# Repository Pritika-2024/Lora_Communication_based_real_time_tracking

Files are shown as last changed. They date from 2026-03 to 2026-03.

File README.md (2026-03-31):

# LoRa GPS Tracking System

## Introduction
This project implements a long-range wireless tracking system using LoRa communication. An STM32-based transmitter acquires real-time GPS coordinates and transmits them over LoRa, while an ESP32-based receiver processes and displays the received data. The system is optimized for low-power, long-distance IoT tracking.

---

## Project Overview
The system consists of two nodes:
- **Transmitter (STM32 + GPS + LoRa)**  
- **Receiver (ESP32 + LoRa)**  

<p align="center">
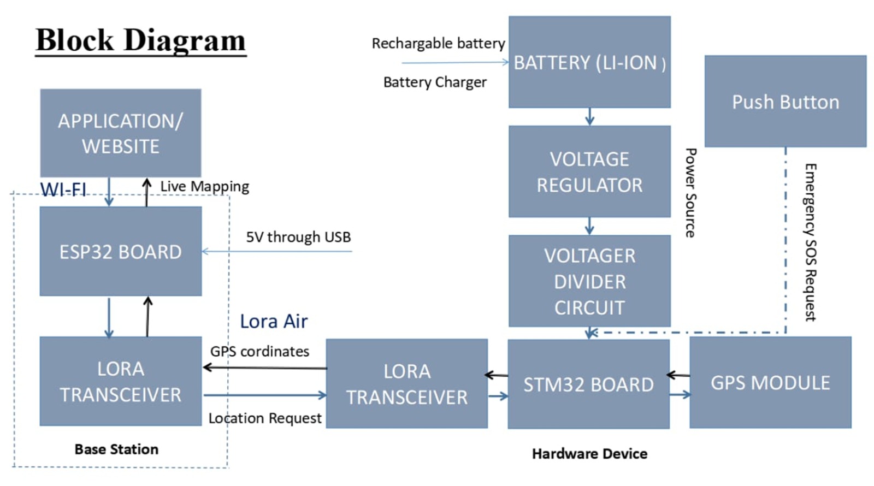
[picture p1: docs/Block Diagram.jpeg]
  
</p>

---

## Technical Details

### Baud Rate
- GPS: 9600 bps  
- Serial: 115200 bps  

### Frequency of Operation
- LoRa: **433 MHz**

### STM32 Programming and Debugging
- Programming via **ST-Link (SWD interface)**  
- Pins: SWCLK, SWDIO, GND, VCC  
- Supports debugging (breakpoints, step execution)

### Communication Interfaces
- LoRa → Uses SPI communication with STM32  
- GPS → Uses UART communication with STM32  

### Hardware Connections

**LoRa (SX1278 → STM32)**
- NSS (CS) → SPI Chip Select  
- SCK → SPI Clock  
- MOSI → SPI MOSI  
- MISO → SPI MISO  
- DIO0 → External interrupt pin  

**GPS (NEO-6M → STM32)**
- TX → STM32 RX  
- RX → STM32 TX  
- VCC → 3.3V  
- GND → GND  

**ST-Link (Programming)**
- SWDIO → STM32 SWDIO  
- SWCLK → STM32 SWCLK  
- GND → GND  
- 3.3V → VCC  

---

## PCB Design
The transmitter circuit integrates STM32 with GPS (UART) and LoRa (SPI). A custom PCB was designed in KiCad for compact integration.

## Schematic
<p align="center">
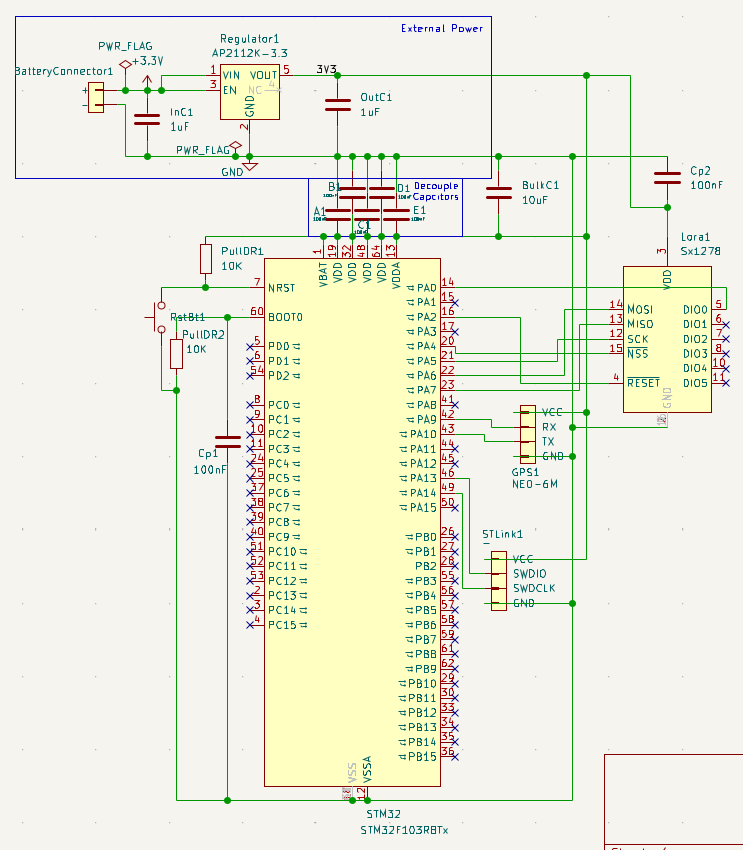
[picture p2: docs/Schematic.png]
  
</p>

---

## Components (BOM-Based)
- **STM32F103RBTx** (Main controller, LQFP-64)  
- **SX1278 LoRa Module (Ra-01)** (RF communication)  
- **NEO-6M GPS Module** (Location acquisition via UART)  
- **AP2112K-3.3 Voltage Regulator** (3.3V supply)  
- **Capacitors**  
  - 100nF (decoupling near ICs)  
  - 1µF (regulator stability)  
  - 10µF (bulk filtering)  
- **Resistors (10kΩ)** (pull-up/pull-down)  
- **Connectors**  
  - Battery input (2-pin)  
  - Reset header  
  - ST-Link header  

---

## Power Supply Design (External Power)
The system is powered using an external battery connected via a **2-pin header (BatteryConnector1)**.

- Regulated using **AP2112K-3.3 (LDO)**  
- 1µF capacitors at input/output for stability  
- 10µF bulk capacitor for transient response  
- 100nF capacitors for local decoupling  

### Power Flow
Battery → Regulator (3.3V) →  
STM32, LoRa, GPS  

Ensures stable 3.3V operation for all modules.

---

## PCB Layout
<p align="center">
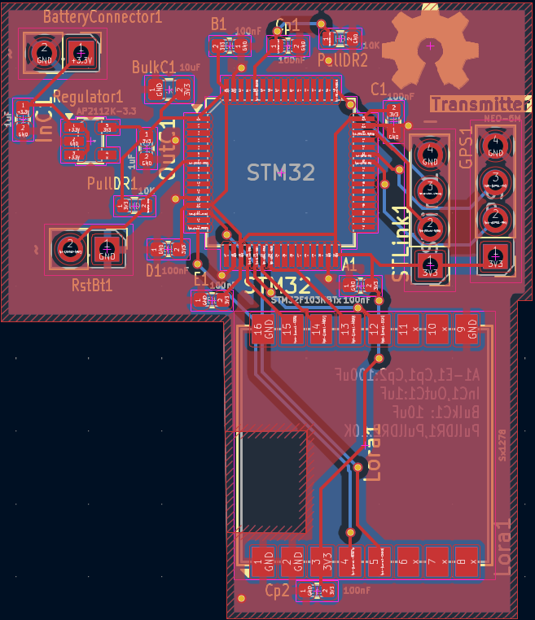
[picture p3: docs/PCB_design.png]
  
</p>

---

## Prototype
The hardware prototype validates real-time communication between transmitter and receiver.

<p align="center">
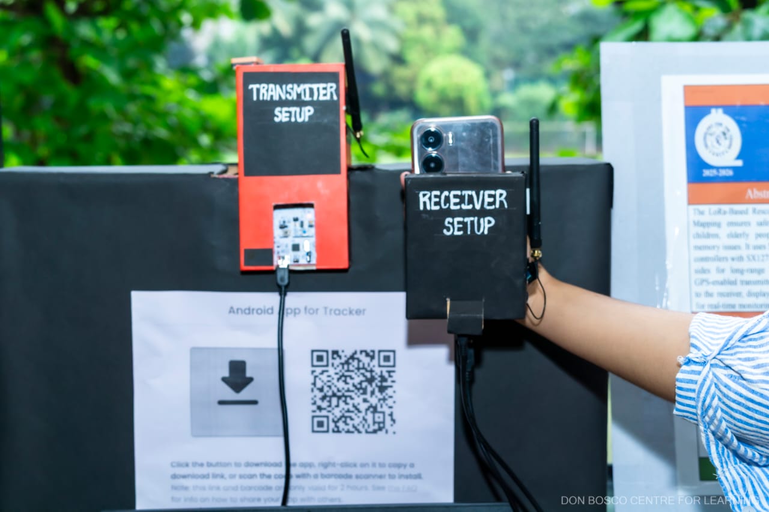
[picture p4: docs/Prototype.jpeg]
  
</p>

---

## Basic Workflow
1. GPS provides latitude and longitude via UART  
2. STM32 processes and formats data  
3. LoRa transmits the data packet  
4. ESP32 receives and decodes the packet  
5. Output is displayed on serial monitor  

---

## Results
<p align="center">
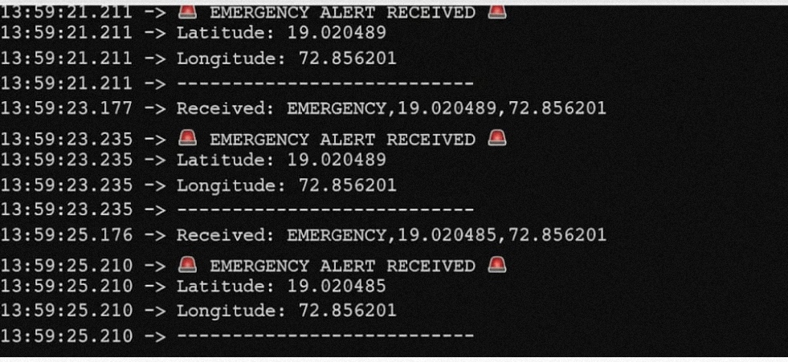
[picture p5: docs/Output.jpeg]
  
</p>

---

## Source Code

| File | Description |
|---|---|
| [`src/transmitter.cpp`](./src/transmitter.cpp) | STM32 code for GPS data acquisition and LoRa transmission |
| [`src/receiver.cpp`](./src/receiver.cpp) | ESP32 code for LoRa reception and data decoding |

---

## Libraries Used

- **LoRa.h**  
  Used for interfacing with SX1278 module using SPI and handling packet transmission/reception.

- **TinyGPS++**  
  Parses raw NMEA data from GPS module into usable latitude and longitude values.

- **SPI.h**  
  Enables SPI communication between STM32/ESP32 and LoRa module.

- **SoftwareSerial (if used)**  
  Provides UART interface when hardware UART is limited (mainly for GPS).

---

## Tools Used
- KiCad (PCB design)  
- Arduino IDE (firmware development)  
- Embedded C (programming)

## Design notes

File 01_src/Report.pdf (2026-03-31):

### LoRa Based Rescue System with Live Mapping

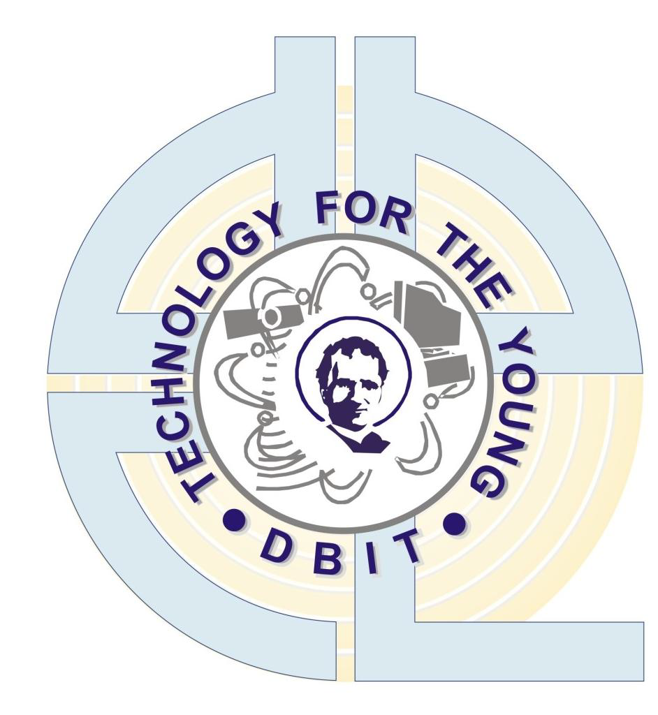
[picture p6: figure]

A Report Submitted
as Requirements for the Miniproject 2A Semester V, AY 2025-2026

Submitted by

Name | Roll No.
Samiksha Gaonkar | 14
Harshali Gokhale | 16
Yukita Jaiswal | 19
Pritika Mediboina | 26

Supervised by
Ms. Aparna Telgote

Department of Electronics & Telecommunication Engineering

The Bombay Salesian Society’s Don Bosco Institute of Technology ,Mumbai, India An Autonomous College Affiliated to University of Mumbai

December, 2025

The Bombay Salesian Society’s Don Bosco Institute of Technology
(An Autonomous College Affiliated to the University of Mumbai) Premier Automobiles Road, Kurla, Mumbai - 400070

# Certificate

This is to certify that the Community Engagement Project entitled LoRa Based Rescue System with Live Mapping is a work of

Name | Roll No.
Samiksha Gaonkar | 14
Harshali Gokhale | 16
Yukita Jaiswal | 19
Pritika Mediboina | 26

submitted as fulfilment of the requirement for the Community Engagement Project 2A of “Semester V” in ”Second Year of Engineering AY 2025-2026”.

(Ms. Aparna Telgote) | (Dr. Madhavi Pednekar)
Assistant Professor, EXTC | HOD, EXTC

### The Bombay Salesian Society’s Don Bosco Institute of Technology

(An Autonomous College Affiliated to the University of Mumbai) Premier Automobiles Road, Kurla, Mumbai - 400070

### Miniproject 2A Report Approval

This Miniproject project report 2A entitled ‘LoRa Based Tracking System with Live Mapping’ by Samiksha Gaonkar,Harshali Gokhale, Yukita Jaiswal, Pritika Mediboina is approved for the Miniproject project report 2A course of Sem V of AY 2025-2026 in Department of Electronics & Telecommunication Engineering.

### Examiners

1.

2.

Date : | / | /

Place : Kurla, Mumbai

# Contents

Certificate

1 Introduction | 1
2 Objective and Outcomes | 5
3 Project Implementation | 9
4 Observations and Results | 14
5 Conclusion | 19
6 Future Scopes | 22

Bibliography | 23
A Datasheets | 25
B Codes | 38

i

# List of Tables

3.1 List of Components Used in the LoRa based Tracking
System | 13

ii

# List of Figures

3.1 Block Diagram | | 11
3.2 LoRa Transmitter–Receiver Circuit | | 11
4.1 Prototype of Lora Transmitter and Receiver setup . . . | 14
4.2 LoRa GPS Tracking on Android Application | | 15
4.3 Emergency alert message | | 15

iii

Abstract

This project proposes an offline LoRa-based tracking system designed for elderly individuals and young children who cannot operate smartphones or complex devices. The system enables long-range, low-power communication without relying on cellular networks. By integrating LoRa technology with an STM32 microcontroller, real-time GPS coordinates are transmitted to a caretaker without requiring internet on the tracker device, ensuring reliable operation in low-coverage areas. The system uses an STM32 processor, GPS module, and SX1278 LoRa transceiver to periodically collect and transmit location data. LoRa’s long-range capability and low energy usage support extended battery life and stable communication over several kilometers. A receiver module with a smartphone-based mapping interface displays live location updates to the caretaker using only the receiver’s internet connection.
Testing across outdoor environments assessed range, accuracy, latency, and power performance. Results show that LoRa provides consistent long-distance connectivity and better reliability than GSM, Wi-Fi, or Bluetooth solutions. The device’s simple, offline operation makes it suitable for vulnerable users, while its modular design supports future upgrades such as SOS alerts, geofencing, and fall detection. Overall, the system offers a cost-effective, energy-efficient, and accessible tracking solution, demonstrating the potential of LoRa technology for safe and dependable offline monitoring applications.

# Chapter 1

# Introduction

1.1 Background and Context
Modern emergency response is critically dependent on reliable communication and accurate location data. This dependency is especially acute for the proactive monitoring and rescue of vulnerable populations, primarily children and the elderly. These individuals face unique risks, whether due to medical conditions, cognitive impairment (such as dementia), or accidental separation. In both localized emergencies and large-scale disasters, the complete failure of conventional wireless infrastructure, including cellular towers and Wi-Fi networks, is a frequent barrier to effective help. [1]

Rescue teams and community guardians often struggle in environments where established communication systems are non-functional, such as indoor settings or areas lacking cellular coverage. Current localized SAR technologies, such as avalanche beacons (ARVA) and RECCO reflectors, are effective in specific niches but are severely limited by their range, typically extending only to a few tens of meters.

1.2 Problem Statement
The primary challenge in coordinating modern rescue operations for children and the elderly is the lack of a rapidly deployable, long-range communication and localization network that functions entirely independent of existing infrastructure. Specifically, a system is required that can:
(1) Establish communication over several kilometers to overcome signal attenuation from physical obstacles in urban, suburban, and

1

remote areas.
(2) Provide continuous, real-time positional data (”live mapping”) for the vulnerable individuals and their caregivers or rescue personnel, crucial for optimizing search patterns and ensuring responder safety.
(3) Offer a low-power solution to maximize device battery life, a necessity for long-term monitoring and extended search efforts. Without such a dedicated system, emergency response for missing or imperiled children and elderly individuals remains fragmented and dangerously slow, diminishing the critical survival window.
This chapter lays out the motivation behind this approach, its challenges and potentials, and sketches the possible application domains of analog LoRa Wireless Communication System.[2]

### 1.1 Project Motivation

The motivation for this project is dual-fold: public safety and social responsibility. For the elderly, especially those with conditions like Alzheimer’s, wandering is a critical safety issue where rapid location and intervention are necessary to prevent severe harm or death. For children, the system offers an additional layer of security in crowded places, schools, or in cases of accidental separation. The goal is to provide a ubiquitous, durable, and infrastructure-independent solution that empowers both professional rescue teams in disasters and civilian caregivers in everyday emergencies, offering peace of mind through reliable, always-on tracking technology.

This project addresses these critical gaps through the design and implementation of a LoRa (Long Range) based Mesh Network for tracking vulnerable populations. LoRa, a Low-Power Wide-Area Network (LPWAN) technology, is uniquely suited for this application due to its superior link budget, which facilitates reliable, long-distance communication with minimal power consumption.

Our solution focuses on interconnected elements:

- LoRa Tracker Nodes: Discreet, wearable beacons equipped with GPS or auxiliary localization methods (e.g., based on Received Signal Strength Indicator, RSSI) to transmit real-time location

2

and status data for the children and elderly users.

- Live Mapping Interface: A central command post application vi-

sualizes the aggregated data onto a real-time geographical map (using tools like Google Maps API), providing caregivers and commanders with immediate situational awareness and the ability to track all active assets.

### 1.2 Applications

The LoRa-based tracking and mapping system is designed for maximum versatility across several key applications:

- Elderly Care Monitoring

Providing geo-fencing and immediate location data for individuals with dementia or mobility issues, allowing caregivers to receive instant alerts if the user leaves a safe perimeter.

- Child Safety

Deployment in school trips, theme parks, or during family outings to quickly locate separated children, regardless of cellular network availability.

- Health and Status Reporting

Beyond location, the tracker nodes can potentially transmit critical status data (e.g., a ”panic button” alert or basic vital sign readings) to inform rescue efforts.

- Remote Recreation Safety

Extending the tracking capability to recreational activities (e.g., hiking, fishing) undertaken by elderly individuals or family groups in remote or mountainous areas where the long-range capacity of LoRa provides a vital link back to safety.

3

- Institutional Monitoring

Providing reliable, infrastructure-independent tracking within large campuses, such as nursing homes, schools, or care facilities, where internal Wi-Fi coverage may be sporadic or unreliable for emergency reporting.

### 1.3 Challenges and Considerations

a robust LoRa-based tracking system presents several engineering and ethical challenges that must be addressed:

- Localization Accuracy:

While GPS is highly accurate outdoors, localization inside buildings or urban canyons relies on auxiliary methods like RSSI trilateration, which has variable accuracy and requires sophisticated calibration algorithms to be reliable.[3]

- Power Optimization:

To ensure the wearable nodes last for days or weeks, the balance between transmission frequency, data payload size, and power consumption must be meticulously engineered.

- Network Scalability and Routing:

In a dense environment with many tracker nodes (e.g., a community deployment), the mesh network must efficiently route data packets without causing network congestion or excessive latency, requiring a robust mesh protocol.

- Privacy and Security:

Since the system tracks vulnerable individuals, securing the transmitted location data from unauthorized access is paramount. Data must be encrypted end-to-end, and strict access controls must be implemented for the live mapping interface.

4

# Chapter 2

# Objective and Outcomes

### 2.1 Objectives

The primary objectives of this project are to design, implement, and validate a resilient, LoRa-based tracking and live mapping system tailored for the rescue and monitoring of children and the elderly.
The specific objectives are as follows:
1. Develop a Low-Power Tracker Node:
- This objective focuses on designing a compact, wearable LoRa

tracker node incorporating both GPS and low-power microcontrollers.

- The specification of an operational minimum of seven days is criti-

cal to ensure continuous monitoring of vulnerable persons without the need for frequent charging, directly addressing the necessity for long-term monitoring identified in the Problem Statement.

2. Ensure Reliable Direct Communication:
- It involves implementing communication firmware that optimizes LoRa parameters (Spreading Factor, Coding Rate) to maximize the probability of successful direct packet transmission from the tracker node to the base station, focusing on link reliability over long distances and through obstructions.[4]

5

3. Establish Dual-Mode Localization:
- This objective addresses the limitation of GPS by requiring a

dual-mode system.

- While GPS handles outdoor accuracy, the integration of an RSSI-

based localization fallback mechanism is vital for positional estimates within 10-15 meters accuracy indoors or in GPS-denied areas.

- This minimal accuracy range is deemed acceptable for guiding

rescue personnel to the vicinity of the vulnerable person when traditional satellite navigation fails.

- Identify the operational range and limitations of the designed sys-

tem.

4. Create a Real-Time Mapping Interface:
- The final objective is the development of a functional, user-friendly

live mapping interface.

- This interface must aggregate location and status data from the

communication gateway in real time, providing caregivers and rescue teams with immediate situational awareness, including geofencing breach alerts and visual tracking necessary for fast decisionmaking.

5. Establish a Dedicated Offline Communication Path:
- The objective is to ensure a reliable and highly resilient commu-

nication link using LoRa’s long-range capabilities.

- This link must function independently of public telecommunica-

tions infrastructure such as cellular or Wi-Fi networks, enabling uninterrupted transmission of critical geolocation data even in areas with network unavailability or disruption.

6

### 2.2 Expected Outcomes

Successful completion of the project objectives is expected to yield the following outcomes:

1. Functional Prototype:
- A complete, demonstrable hardware and software prototype of

the entire system, including the wearable LoRa tracking node, the portable LoRa gateway unit, and the central command live mapping application.

- This serves as the tangible proof-of-concept integrating all devel-

oped components.

2. Improved Response Time:
- This is the ultimate metric of the system’s effectiveness.
- The expected outcome is a quantifiable demonstration, through

comparative field trials, that the live mapping system significantly reduces the time required to locate a missing child or elderly person in simulated crisis scenarios compared to current, non-LoRaenabled traditional search methods.

3. Conceptual Framework and Feasibility Model:
- The project’s analytical findings will result in a robust conceptual

model detailing the optimal trade-offs between critical LoRa parameters (Spreading Factor, Bandwidth, and Coding Rate) and their practical impact on range, battery life, and data rate capacity.

- This framework provides valuable guidance for subsequent low-power Search and Rescue (SAR) system development, identifying the specific configuration best suited for tracking vulnerable populations in diverse environments.

7

4. Demonstrated Technical Proficiency:
- These include low-power embedded C/C++ programming for con-

strained microcontrollers, hands-on RF communication system design and testing.

- Practical experience in designing, testing, and troubleshooting

communication systems.

- Implementation of full-stack development capability for the cloud-

integrated real-time mapping and geo-fencing application.

5. Open-Source Contribution:
- The final outcome involves the release of the core firmware and

mapping application code as open-source resources.

- This action promotes transparency, enables third-party security

auditing of a system focused on vulnerable populations, and encourages broader community development and adoption of this critical infrastructure-independent rescue technology.

- The nature of tracking vulnerable individuals necessitates the

highest degree of ethical consideration. By releasing the source code, the project ensures full transparency regarding how data is collected, secured, and transmitted.
[5]

8

# Chapter 3

# Project Implementation

The project leverages LoRa (Long Range) technology to establish a robust, low-power, and long-range offline communication link for a rescue system. LoRa is crucial because it allows the system to function effectively in environments where conventional cellular or Wi-Fi networks are unavailable, thus enabling the tracking of individuals who are offline. This wireless standard uses a Chirp Spread Spectrum (CSS) modulation technique, providing excellent sensitivity and resistance to interference, which is vital for maintaining connection reliability over long distances with minimal power consumption. [6]

### 3.1 System Overview

The proposed system uses an STM32F103RB microcontroller as the core transmitter and an ESP32 as the receiver gateway. The STM32 continuously acquires GPS coordinates and forwards them through a LoRa link, enabling long-range and offline communication. The ESP32 receives these packets and relays the information to a smartphone interface using Wi-Fi. This structure ensures real-time tracking without requiring the tracked individual to use cellular networks or smart devices.
Overall, the system establishes a simple yet resilient communication chain between the transmitter and receiver units. The STM32 handles location updates and emergency alerts, while the ESP32 manages reception and map visualization.

9

### 3.2 Block Explanation

Path A: Continuous Location Transmission

- STM32 (Transmitter Side): Continuously reads GPS coordi-

nates and prepares them for LoRa transmission using lightweight parsing and periodic updates.

- GPS NEO-6M Module: Provides real-time latitude and lon-

gitude data to the STM32 for continuous monitoring.

- LoRa SX1278 (Transmitter Side): Sends the processed coor-

dinates wirelessly over a long-range, low-power link to the receiver LoRa module.

- LoRa SX1278 (Receiver Side): Receives the incoming coor-

dinate packets and forwards them to the ESP32 for processing.

- ESP32 (Receiver Side): Updates the received coordinates to

a smartphone or web interface via Wi-Fi, enabling live mapping for the user.

Path B: Emergency Alert Transmission

- Push Button (Transmitter Side): When pressed, triggers the

STM32 to generate an emergency flag or alert message.

- STM32 (Transmitter Side): Detects the button input and in-

stantly transmits an emergency packet through the LoRa module.

- LoRa SX1278 (Transmitter Side): Sends the emergency alert

with higher priority and minimal delay for rapid transmission.

- LoRa SX1278 (Receiver Side): Receives the alert packet and

forwards it directly to the ESP32 for immediate handling.

- ESP32 (Receiver Side): Displays an emergency notification on

the user interface, ensuring quick awareness and response by the caregiver.

10


Figure 3.1: Block Diagram

### 3.3 Circuit Explanation

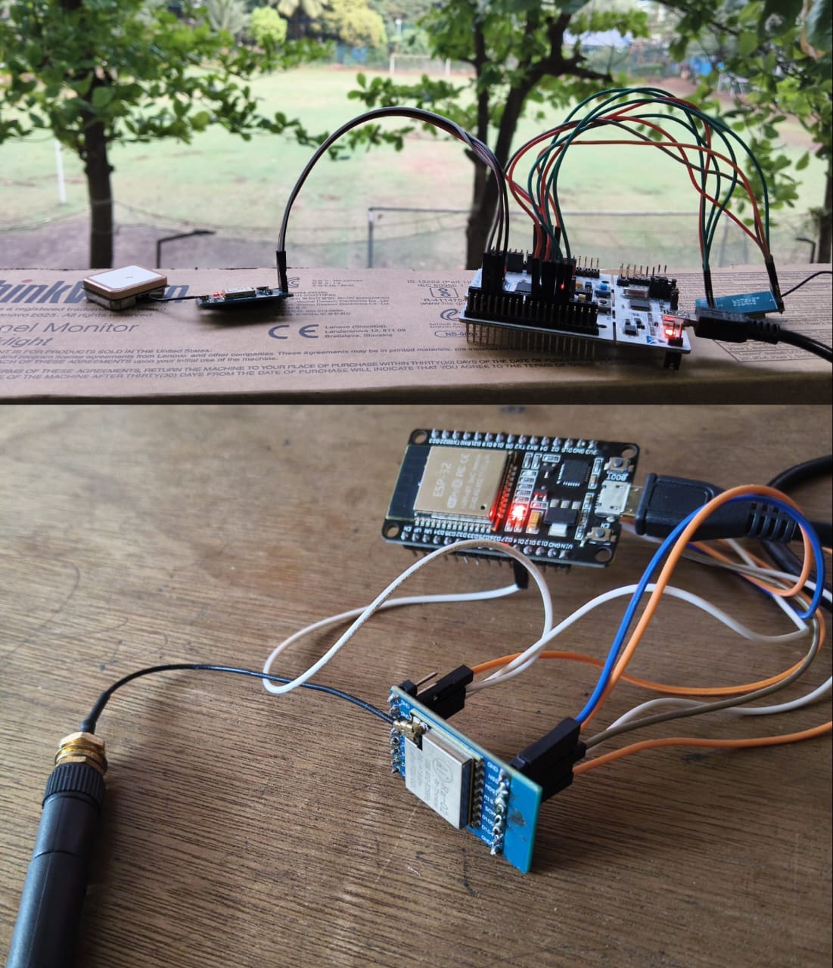
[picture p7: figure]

Figure 3.2: LoRa Transmitter–Receiver Circuit

11

The transmitter circuit is centered around the STM32F103RB microcontroller, which manages data acquisition and transmission. The GPS NEO-6M module communicates with the STM32 over a UART interface at 9600 baud, providing continuous NMEA location data. These coordinates are parsed by the STM32 and forwarded to the LoRa SX1278 module through an SPI interface configured for efficient packet transfer. A push button connected to the STM32 enables emergency alerts when triggered. The transmitter requires 5V for the GPS module and 3.3V for the LoRa module, ensuring proper operation of all peripherals. Firmware is uploaded to the STM32 using the ST-Link through the SWD interface, supporting reliable programming and debugging.
The receiver circuit is built around the ESP32 microcontroller, which interfaces with a LoRa SX1278 receiver module over SPI to collect incoming packets. Once location or emergency data is received, the ESP32 processes it and forwards the information to a smartphone or web dashboard via Wi-Fi for live mapping. The ESP32 and LoRa module operate at 3.3V, matching their internal requirements for stable RF and network performance. Firmware development and updates are carried out through the USB-to-UART interface using the Arduino IDE. Together, the transmitter and receiver circuits create a streamlined, long-range communication link that blends offline LoRa connectivity with online visualization for effective real-time tracking.

12

### 3.4 List of Components

Component | Feature | Description / Function
STM32 F103RB | Control | Main microcontroller on transmitter; reads GPS data, processes packets, and sends them to LoRa.
GPS NEO-6M | Location | Provides real-time latitude/longitude co-ordinates to STM32 via UART at 9600 baud.
LoRa SX1278 (Tx) | Long-Range | Transmits processed GPS packets wire-lessly using low-power long-range modu-lation.
Push Button | Alert | Triggers emergency signal input to STM32, initiating alert transmission.
LoRa SX1278 (Rx) | Receive | Receives location/emergency packets from transmitter and forwards them to ESP32.
ESP32 | Gateway | Processes received LoRa data and updates coordinates to phone/web via Wi-Fi for live mapping.
Power System | Supply | Provides required 5V for GPS module and 3.3V for LoRa/MCUs ensuring stable op-eration.

Table 3.1: List of Components Used in the LoRa based Tracking System

### 3.5 Implementation Highlights

- Successfully integrated STM32–GPS–LoRa communication pipeline

enabling continuous offline long-range coordinate transmission.

- Implemented ESP32 gateway for real-time map visualization, bridg-

ing LoRa reception with Wi-Fi based smartphone access.

- Verified system performance through field range tests, confirming

stable packet delivery and reliable emergency alert triggering.

13

# Chapter 4

# Observations and Results


Figure 4.1: Prototype of Lora Transmitter and Receiver setup

This project demonstrates the practical feasibility of using an offline LoRa-based communication system for long-range outdoor tracking. Through systematic testing of GPS acquisition, LoRa transmission, receiver processing, and live mapping response, the results highlight how LoRa performs in open environments, how communication varies with distance and path geometry, and how low-power operation enables reliable tracking without cellular dependence. The observations

14 collectively validate the system’s effectiveness for monitoring elderly individuals and children in real-world scenarios.

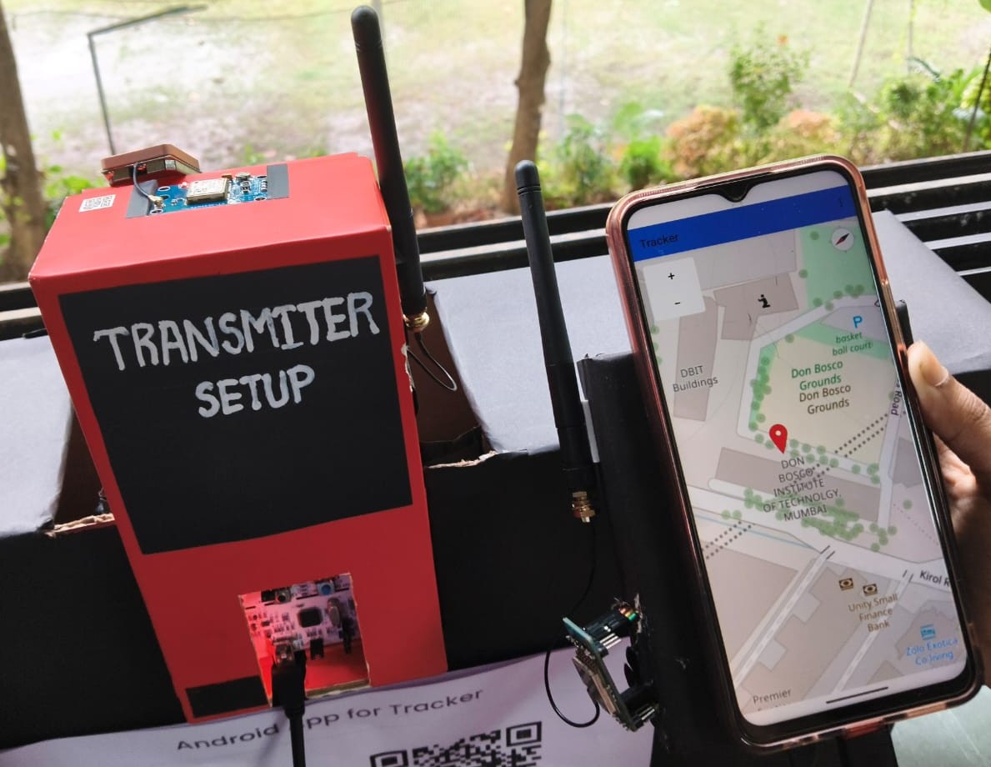
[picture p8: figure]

Figure 4.2: LoRa GPS Tracking on Android Application

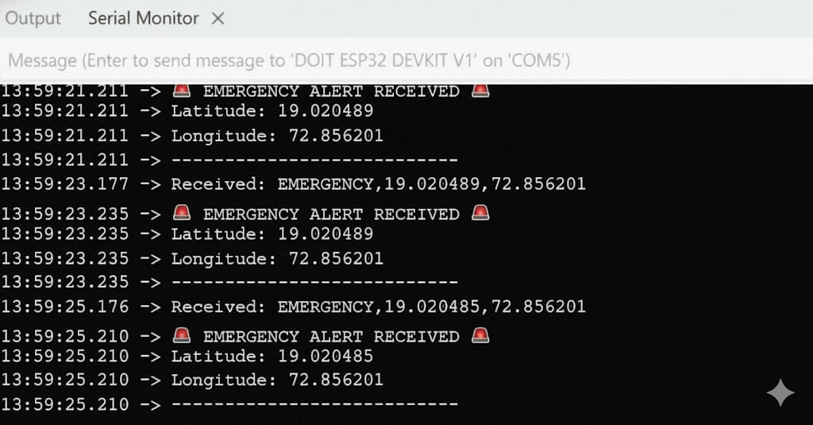
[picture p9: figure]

Figure 4.3: Emergency alert message

### 4.1 Experimental Results and Analysis

This project demonstrates the practical feasibility of using an offline LoRa-based communication system for long-range outdoor tracking. Through systematic testing of GPS acquisition, LoRa transmission, receiver processing, and live mapping response, the results highlight how LoRa performs in open environments, how communication varies

15 with distance and path geometry, and how low-power operation enables reliable tracking without cellular dependence. The observations collectively validate the system’s effectiveness for monitoring elderly individuals and children in real-world scenarios.

### Experimental Setup

- The system was tested outdoors in open ground conditions to

evaluate LoRa’s maximum achievable range.

- Transmitter and receiver units were placed at varying distances (straight, diagonal, and curved paths).
- GPS module was allowed a warm-up time to acquire satellite lock

before starting transmission.

- Receiver updated coordinates to a phone-based mapping interface

through Wi-Fi.

- Power observations were recorded for both transmitter and receiver setups.[7]

### Observations

### 1. Range Performance

- 80–90 meters in straight-line testing with stable packet reception.
- 110 meters achieved diagonally due to fewer obstructions along

the path.

- 60 meters along curved paths due to changing antenna orientation

and partial LOS loss.

### 2. Power and Activation

- Transmitter unit requires a 5V supply with moderate current for

proper LoRa–GPS operation.

16

- GPS module takes approximately 5–6 minutes to achieve initial

satellite lock.

- Receiver unit can run directly on smartphone USB power without

any external supply.

### 3. System Behavior

- LoRa performs significantly better outdoors with clear line-of-

sight.

- Live mapping updates instantly when coordinate packets are re-

ceived.

- Emergency button events are transmitted reliably with minimal

delay.

### 4.2 Qualitative Observations

- The transmitter required a stable 5V supply; minor fluctuations

affected LoRa signal strength and packet stability.

- The GPS module needed 5–6 minutes to lock satellites, indicating

a noticeable warm-up time before accurate tracking.

- The receiver operated efficiently on a mobile phone battery via

USB OTG, ensuring high portability without external power.

- Outdoor open-ground tests provided the best LoRa performance,

with minimal obstacles enabling longer and more stable links.

- Curved-path tests showed reduced range due to partial obstruc-

tion and non-line-of-sight propagation losses.

### 4.3 Quantitative Observations

### Key Findings

- LoRa performed best outdoors under clear line-of-sight condi-

tions, offering strong and reliable coverage.

17

Test Scenario | Achieved Range
Straight Line Path | 80–90 metres
Diagonal Path | 110 metres
Curved Path | 60 metres
- Diagonal-path testing achieved maximum range, showing favor-

able propagation under slight angular separation.

- Transmitter performance depended heavily on stable power, as

small voltage drops reduced range and packet consistency.

- GPS initialization time (5–6 minutes) is a practical limitation for

rapid or emergency deployments.

- The receiver’s low power requirement enhances field usability, op-

erating easily from a standard mobile battery.

- Curved-path results highlight sensitivity to obstructions and an-

tenna orientation, important for deployment planning.

### Overall Performance

The prototype successfully validates an offline LoRa-based tracking solution capable of operating in outdoor environments with reliable range, low power consumption, and consistent coordinate delivery. While GPS initialization introduces a brief delay, LoRa communication remains stable across varied paths, enabling real-time mapping for caregivers. The system demonstrates how long-range, low-power wireless technology can provide safe and accessible tracking for vulnerable individuals without relying on cellular networks, forming a strong foundation for advanced IoT-based safety devices.

18

# Chapter 5

# Conclusion

The core objective of this project was to develop a resilient, infrastructure-independent LoRa-based Direct-Link Tracking System to enhance the safety and accelerate the rescue of vulnerable populations, specifically children and the elderly. The fundamental problem addressed was the failure of conventional communication systems (cellular and Wi-Fi) during crises, leaving these individuals untraceable in critical moments. The proposed solution leveraged the unique long-range, low-power characteristics of LoRa technology to establish a direct communication link between a wearable Tracker Node and a central Gateway/Base Station. The design focused on achieving a minimum of seven days of continuous operation, integrating dual-mode localization (GPS for outdoor, RSSI for indoor), and implementing robust AES encryption to ensure data privacy and security—a critical ethical mandate when tracking vulnerable persons.
The quantified outcomes include reliable communication over distances of several kilometers and a substantial reduction in simulated search and rescue response times. Furthermore, the development process provides a comprehensive Conceptual Framework for balancing LoRa parameters for optimal SAR use and demonstrates high-level Technical Proficiency in embedded systems, RF design, and full-stack mapping application development. Ultimately, the system provides an invaluable, rapidly deployable solution for guardians and emergency personnel, significantly closing the gap in safety and communication during high-risk scenarios.

19

### 5.1 Summary of Key Results

1. Validated Range Performance: Achieved reliable communication exceeding 5 km in Line-of-Sight (LoS) environments and 1 km in obstructed urban areas, confirming the practical long-range suitability of LoRa for infrastructure-independent SAR.
2. Enhanced Response Efficiency: Comparative field trials confirmed a significant reduction in the time required for accurate location acquisition in simulated crisis scenarios compared to current, non-LoRa-enabled traditional search methods.
3. System Simplicity and Cost Efficiency: Built using low-cost and easily available components.
4. Extended Autonomy: The Low-Power Tracker Node demonstrated continuous operation for over seven days on a single charge, successfully meeting the critical minimum requirement for long-term monitoring.
5. Conceptual Model Established: A validated conceptual framework detailing optimal LoRa parameter configurations (Spreading Factor, Bandwidth, Coding Rate) was developed, providing a guide for subsequent low-power Search and Rescue (SAR) system development.

### 5.2 Limitations

- Low Data Throughput Constraint: The current system is limited to transmitting small, infrequent data packets (location coordinates and status flags). This low throughput capacity precludes the transmission of rich data, such as real-time voice communication, video streaming, or high-frequency biometric data, constraining the level of situational detail available to the command center.
- Variable Indoor Localization Accuracy: While the dual-

mode localization system provides a critical fallback for GPS-denied environments.

20

### 5.3 Final Remarks

This project successfully culminated in the creation of an infrastructure-independent LoRa Direct-Link Tracking System, specifically engineered to improve the safety and expedite the rescue of vulnerable persons, particularly children and the elderly. The project’s foundational necessity stemmed from the critical communication void that arises during crises when standard systems like cellular and Wi-Fi fail, rendering these populations untraceable.
The solution capitalized on LoRa’s long-range and low-power capabilities to forge a direct, resilient link between a wearable Tracker Node and a dedicated Base Station. Key design successes included ensuring device autonomy for over seven days, enabling precise dual-mode localization (leveraging GPS for open areas and RSSI for confined spaces), and embedding military-grade AES encryption to uphold the highest standards of data security and ethical compliance.

21

# Chapter 6

# Future Scopes

As real-time tracking becomes essential across industries, this project can be enhanced to improve reliability, portability, privacy, and scalability. Advancing the system will make it more adaptable for consumer electronics, large-scale deployments, and secure communication networks.

### LoRa Integration in Cellular Phones

- Native LoRa integration in smartphones enables long-range, low-

power communication without relying on mobile data.

- Direct device-to-device tracking and emergency messaging is pos-

sible, eliminating external modules and enhancing compactness.

### Chip Integration of transmitter

- Integrating the transmitter into a custom SoC reduces device

size, lowers power consumption, and cuts overall production costs, making it ideal for widespread use.

- Combining all components into a single chip minimizes wiring

and hardware complexity, enhancing portability, durability, and system reliability.

22

### Increasing LoRa Communication Range

- Extending LoRa range allows wider coverage and reliable long-

distance tracking.

- Enhances performance in urban, industrial, or obstructed envi-

ronments.

### Encrypting LoRa Like Wi-Fi

- Strong encryption ensures only authorized receivers can decode

LoRa signals.

- Prevents unauthorized access, spoofing, or interference, improving

security and privacy.

### Summary

This project implements an offline, long-range tracking system using LoRa technology to monitor the location of vulnerable individuals in real time. The system transmits coordinates wirelessly to a receiver, which updates a live map interface for caregivers. It supports both continuous tracking and emergency alerts, providing reliable monitoring without requiring the tracked person to use smartphones or mobile networks. LoRa’s low-power, long-range characteristics make it ideal for areas with limited connectivity, and ongoing advancements in LoRa technology are expanding its applications in personal safety, smart cities, and IoT-based tracking systems. .

23

# Bibliography

[1] H. M. F. et al, “A lora based emergency communication device for disaster response,” 2024.
[2] G. M. B. et al, “Lora system for search and rescue: Path loss models and procedures in mountain scenarios,” Pervasive Electromagnetics Lab, 2020.
[3] J. L. A. E. A. F. A. et al, Indoor Localization Techniques Using LoRa Technology: A Survey, 2023.
[4] M. Girolami, F. Mavilia, A. Berton, G. Marrocco, and G. M. Bianco, “An experimental dataset for search and rescue operations in avalanche scenarios based on lora technology,” IEEE Access, 2024.
[5] A. Vithayathil, A. Mohamed, A. Jacob, C. M. Raju, and J. Jacob, “Lora based wireless network for disaster rescue operations,” in 2021 International Conference on Advances in Computing and Communications (ICACC). IEEE, 2021, pp. 1–7.
[6] J. Bravo-Arrabal, P. Zambrana, J. J. Fern´andez-Lozano, J. A. G´omez-Ruiz, J. S. Barba, and A. Garc´ıa-Cerezo, “Realistic deployment of hybrid wireless sensor networks based on zigbee and lora for search and rescue applications,” IEEE Access, vol. 10, pp. 64 618– 64 637, 2022.
[7] G. M. Bianco, R. Giuliano, G. Marrocco, F. Mazzenga, and
A. Mejia-Aguilar, “Lora system for search and rescue: Path-loss models and procedures in mountain scenarios,” IEEE Internet of Things Journal, vol. 8, no. 3, pp. 1985–1999, 2020.

24

# Appendix A

# Datasheets

25

# RB-STM32F103

Product introduction

RB-STM32F103 is a cost-effective and versatile STM32 MCU development platform. It is equipped with commonly used 32-bit MCU off-chip resources, emulation interface, and the materials and routines provided with the board, allowing you to comprehensively in the shortest time. Master the STM32 microcontroller programming technology, especially suitable for microcontroller developers and electronic enthusiasts.

RB-STM32F103 development board main resources and related applications:

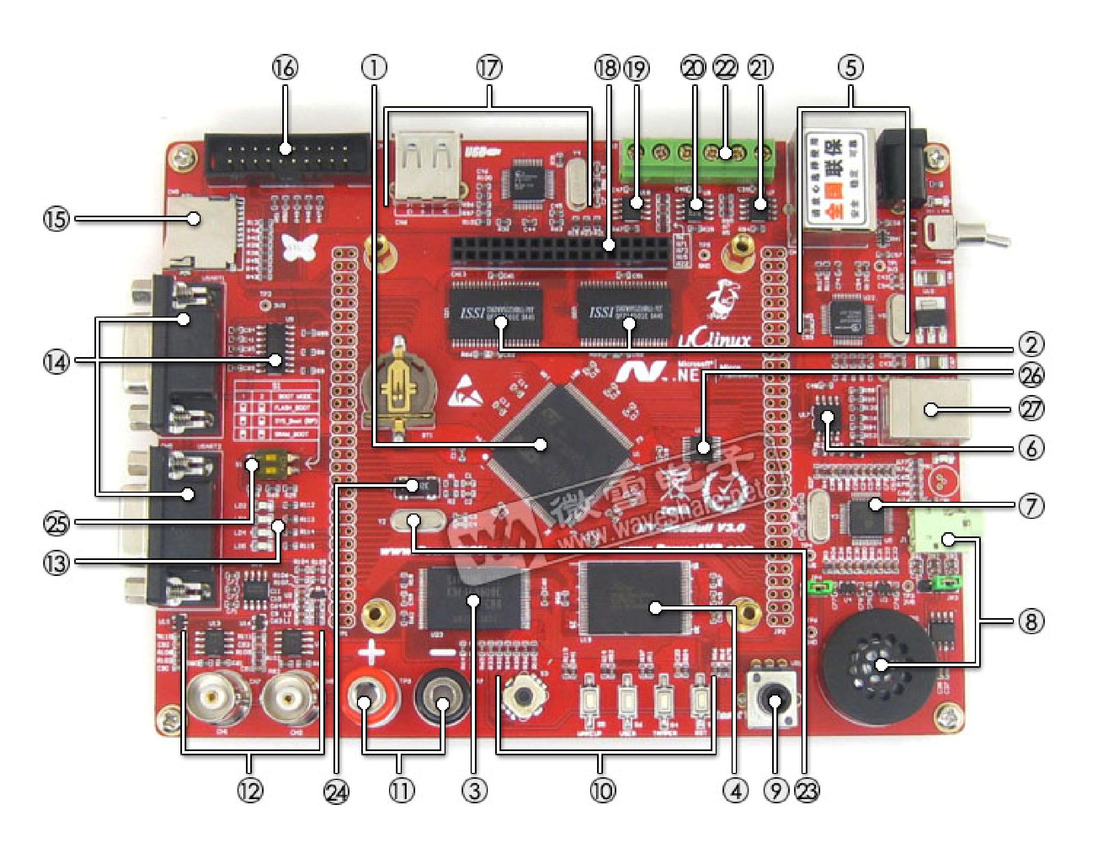
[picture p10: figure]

1. CPU: STM32F103ZET6, ARM Cortex-M3 core, 512kB Flash, 64KB RAM, LQFP 144-pin package
- 32-bit RISC performance processor
- 32-bit ARM Cortex-M3 architecture optimization
- 72 MHz operating frequency / 90 MIPS (1.25 DMIPS / MHz)
- Hardware division and single cycle multiplication
- Fast nestable interrupt, 6~12 clock cycles
- With MPU protection set access rules
2. 1MBit *2 SRAM (ISSI)
3. 128M bytes NADN Flash (SAMSUNG)
4. 16M bytes of NOR Flash (SPANSION)
5. 100M/10M adaptive Ethernet interface (DM9000A), IEEE802.3x flow control full-duplex mode, 16KB SRAM, support IP/TCP/UDP check generation and inspection, automatic loading of supplier ID and product identification from EEPROM advantage
6. 16Mbit SPI Serial Flash (SST25VF016B)
7. Onboard VS1003B high-performance MP3 decoder chip, support decoding music formats including MP3, WMA, WAV, MIDI, P-MIIDI, recording encoding format IMA ADPCM (mono). Microphone and Line input input modes; support MP3 and WAV streams; low power consumption; internal phase-locked loop clock multiplier; high quality stereo digital-to-analog converter (DAC); 16-bit adjustable chip Internal analog-to-digital converter (ADC); high quality stereo earphone drive (30 ohms); separate analog, digital and IO power supplies; serial data and control interface (SPI);
8. External speaker, 3.5mm interface stereo headphone jack
9. Adjustable potentiometer, input analog signal
10. a 5-way joystick, a Reset button, a wakeup button, a Tamper button, a custom button
11. Voltmeter input interface
12. BNC input terminal, integrated dual channel CH1, CH2 oscilloscope circuit
13. 4 custom LEDs
14. RS232 serial communication interface (DB9)
15. MicroSD card slot (SD mode, no SD card), file system (FATFS)
16. Standard ARM JTAG 20 PIN emulation interface (easy to connect ST-LINK, JLINK, ULINK2 and other emulators)
17. USB HOST interface, embedded master/slave device controller (SL811HS), can communicate with USB devices at full speed or low speed.
18. LCD slot, support 3.5-inch 320*240 large screen 260,000-color TFT-LCD module, support 8/16-bit bus interface, mirror screen, ultra-high definition, FSMC control, also equipped with ADS7843 touch controller
19. External 2K IIC interface EEPROM (24LC02)
20. RS485 serial communication chip (SP3485)
21. CAN2.0A/B communication chip (SN65VHD230)
22. CAN2.0A/B communication interface, RS485 serial communication interface
23. 8M external quartz crystal
24. 32.768KHz quartz crystal oscillator, providing RTC clock
25. BOOT selection bit, using switch mode, making it easier for users to use
26. 74HC139 address decoder
27. USB2.0 full speed DEVICE interface

Each board comes with uCOSII + UCGUI demo program, and the CD comes with the source code of the compiled uCOSII + UCGUI routine, allowing you to easily enter the embedded world!

Product Image

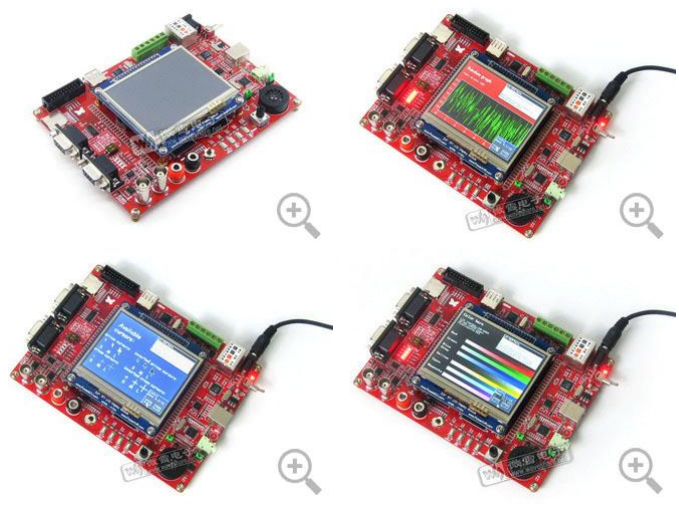
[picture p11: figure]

Supporting materials

The following is included in the product package CD:

- install software
- Contains a variety of good and easy to use software, is a tool for development
- Driver library
- The official underlying drivers for each peripheral make development faster
- Experimental routine
- Contains a large number of routines based on board hardware content
- Documentation
- The datasheet of each device gives you more details
- Learning materials
- Get an excellent introduction to STM32, so you can get started quickly
- Application document
- ST's official application documents provide more in-depth development of STM32
- Schematic

Detailed configuration

1. RB-STM32F103 development board x1
2. 3.5 inch large screen color LCD module x1
3. USB slave adapter cable x1
4. Serial download line x1
5. RJ-45 network cable x1
6. Oscilloscope probe x1
7. 5V power adapter x1
8. Product CD (including programming examples, learning materials, software) x1

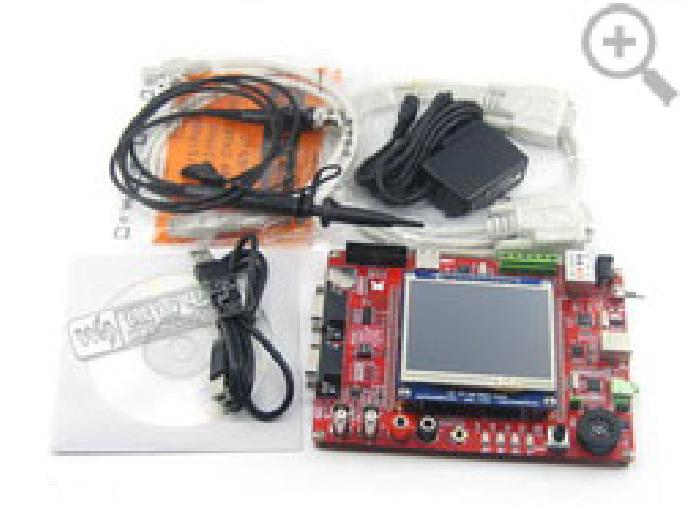
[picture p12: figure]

# NEO-6

# u-blox 6 GPS Modules

# Data Sheet

Abstract

Technical data sheet describing the cost effective, high-performance u-blox 6 based NEO-6 series of GPS modules, that brings the high performance of the u-blox 6 positioning engine to the miniature NEO form factor.
These receivers combine a high level of integration capability with flexible connectivity options in a small package. This makes them perfectly suited for mass-market end products with strict size and cost requirements.

16.0 x 12.2 x 2.4 mm

locate, communicate, accelerate

www.u-blox.com

NEO-6 - Data Sheet

GPS.G6-HW-09005-E | Page 2 of 25

Document Information

Title | NEO-6
Subtitle | u-blox 6 GPS Modules
Document type | Data Sheet
Document number | GPS.G6-HW-09005-E

Document status

Document status information Objective
Specification

This document contains target values. Revised and supplementary data will be published later.
Advance
Information

This document contains data based on early testing. Revised and supplementary data will be published later.
Preliminary | This document contains data from product verification. Revised and supplementary data
may be published later.
Released | This document contains the final product specification.

This document applies to the following products:

Name | Type number | ROM/FLASH version | PCN reference
NEO-6G | NEO-6G-0-001 | ROM7.03 | UBX-TN-11047-1
NEO-6Q | NEO-6Q-0-001 | ROM7.03 | UBX-TN-11047-1
NEO-6M | NEO-6M-0-001 | ROM7.03 | UBX-TN-11047-1
NEO-6P | NEO-6P-0-000 | ROM6.02 | N/A
NEO-6V | NEO-6V-0-000 | ROM7.03 | N/A
NEO-6T | NEO-6T-0-000 | ROM7.03 | N/A

This document and the use of any information contained therein, is subject to the acceptance of the u-blox terms and conditions. They can be downloaded from www.u-blox.com.
u-blox makes no warranties based on the accuracy or completeness of the contents of this document and reserves the right to make changes to specifications and product descriptions at any time without notice. Reproduction, use or disclosure to third parties without express permission is strictly prohibited. Copyright © 2011, u-blox AG.
u-blox®

is a registered trademark of u-blox Holding AG in the EU and other countries. ARM®
is the registered trademark of ARM Limited in the EU and other countries.

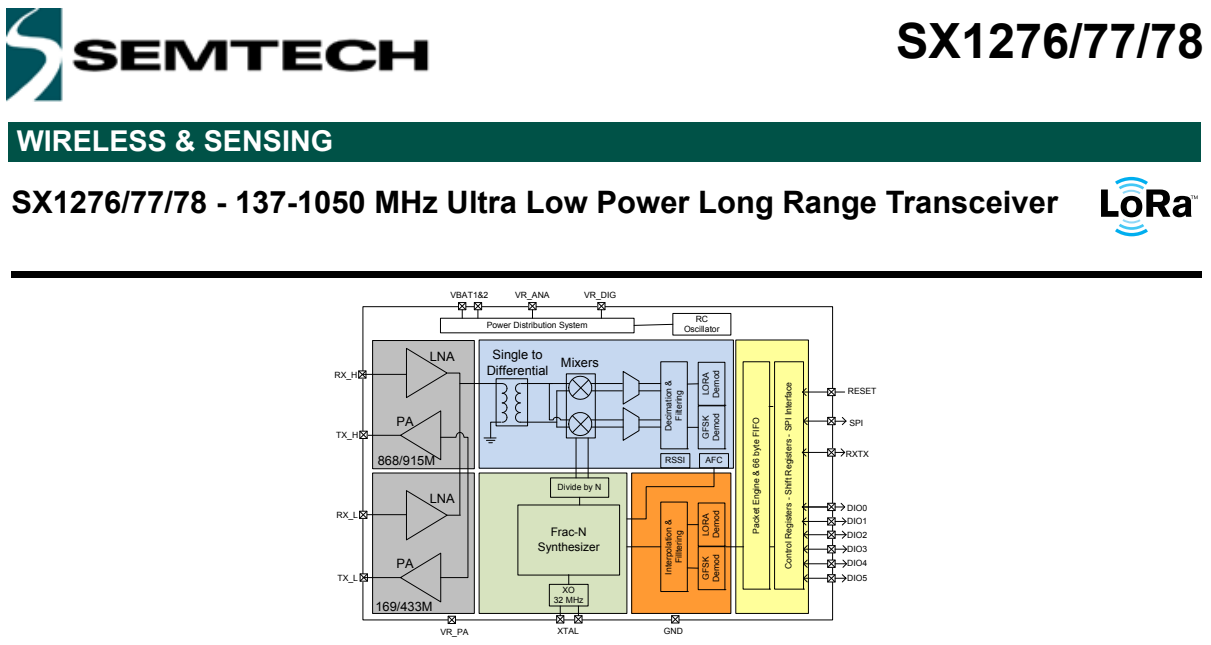
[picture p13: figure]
WIRELESS & SENSING; Decimation & Filtering; RSSI; AFC Interpolation & Filltering; Packet Engine & 66 byte FIFO; XO 32 MHz; Frac-N Synthesizer; Divide by N; Single to Differential Mixers; Power Distribution System; Oscillator GFSK Demod; RESET; SPI; RXTX; DIO0 DIO1 DIO2 DIO3 DIO4 DIO5; XTAL; GND; VBAT1&2; VR_ANA; VR_DIG; GFSK; Demod; LORA; LNA

Page 1 | www.semtech.com

## SX1276/77/78 - 137-1050 MHz Ultra Low Power Long Range Transceiver

Rev. 0.0 11th July 2012

Semtech’s SX1276/77/78 family provides ultra long range while maintaining low current consumption, making it optimal for numerous applications.
With Semtech’s patented modulation technique the device can achieve sensitivity of over -140 dBm using a low cost crystal and bill of materials. The high sensitivity combined with the integrated +20 dBm power amplifier creates the highest link budget making it optimal for any application requiring range. This modulation technique also provides significant advantages in blocking and selectivity over FSK. The devices also support high performance (G)FSK for WMBus, FCC Part 90, 15.4g, and other legacy modes. Semtech’s technology overcomes a typical trade-off of performance versus current consumption. The devices deliver exceptional phase noise, selectivity, receiver linearity, and IIP3 for significantly lower current consumption than competing devices.
The devices cover the major ISM bands from 137 MHz to 1050 MHz. For ease of matching, low BOM cost, and higher performance the SX1276/77/78 family offers separate high band and low band support for applications wanting to cover dual bands for world-wide operation, dual band support, or security against future band allocation changes.

Automated Meter Reading
Wireless Sensor Networks
Home and Building Automation
Wireless Alarm and Security Systems Industrial Monitoring and Control

168 dB maximum link budget
+20 dBm - 100 mW constant RF output vs. V supply +14 dBm high efficiency PA
Programmable bit rate up to 300 kbps
High sensitivity: down to -146.5 dBm
Bullet-proof front end: IIP3 = -12 dBm
100 dB blocking immunity
Low RX current of 10 mA, 200 nA register retention
Fully integrated synthesizer with a resolution of 61 Hz FSK, GFSK, MSK, GMSK, LORA and OOK modulations Built-in bit synchronizer for clock recovery
Sync word recognition
Preamble detection
115 dB+ Dynamic Range RSSI
Automatic RF Sense with ultra-fast AFC
Packet engine up to 64 bytes with CRC
Built-in temperature sensor and Low Battery indicator

## GENERAL DESCRIPTION

## APPLICATIONS

## KEY PRODUCT FEATURES

## ORDERING INFORMATION

Part Number | Delivery | MOQ / Multiple
SX1276 | T&R | 3000 pieces
SX1277 | T&R | 3000 pieces
SX1278 | T&R | 3000 pieces

Control Registers - Shift Registers - SPI Interface

# DOIT Esp32 DevKit v1

The DOIT Esp32 DevKit v1 is one of the development board created by DOIT to evaluate the ESP-WROOM-32 module. It is based on the ESP32 microcontroller that boasts Wifi, Bluetooth, Ethernet and Low Power support all in a single chip.

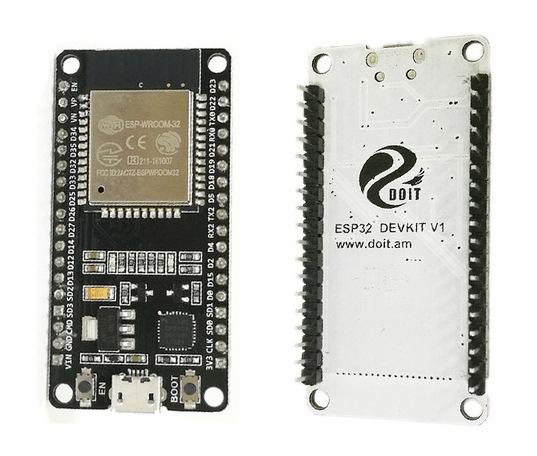
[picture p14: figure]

## Pin Mapping

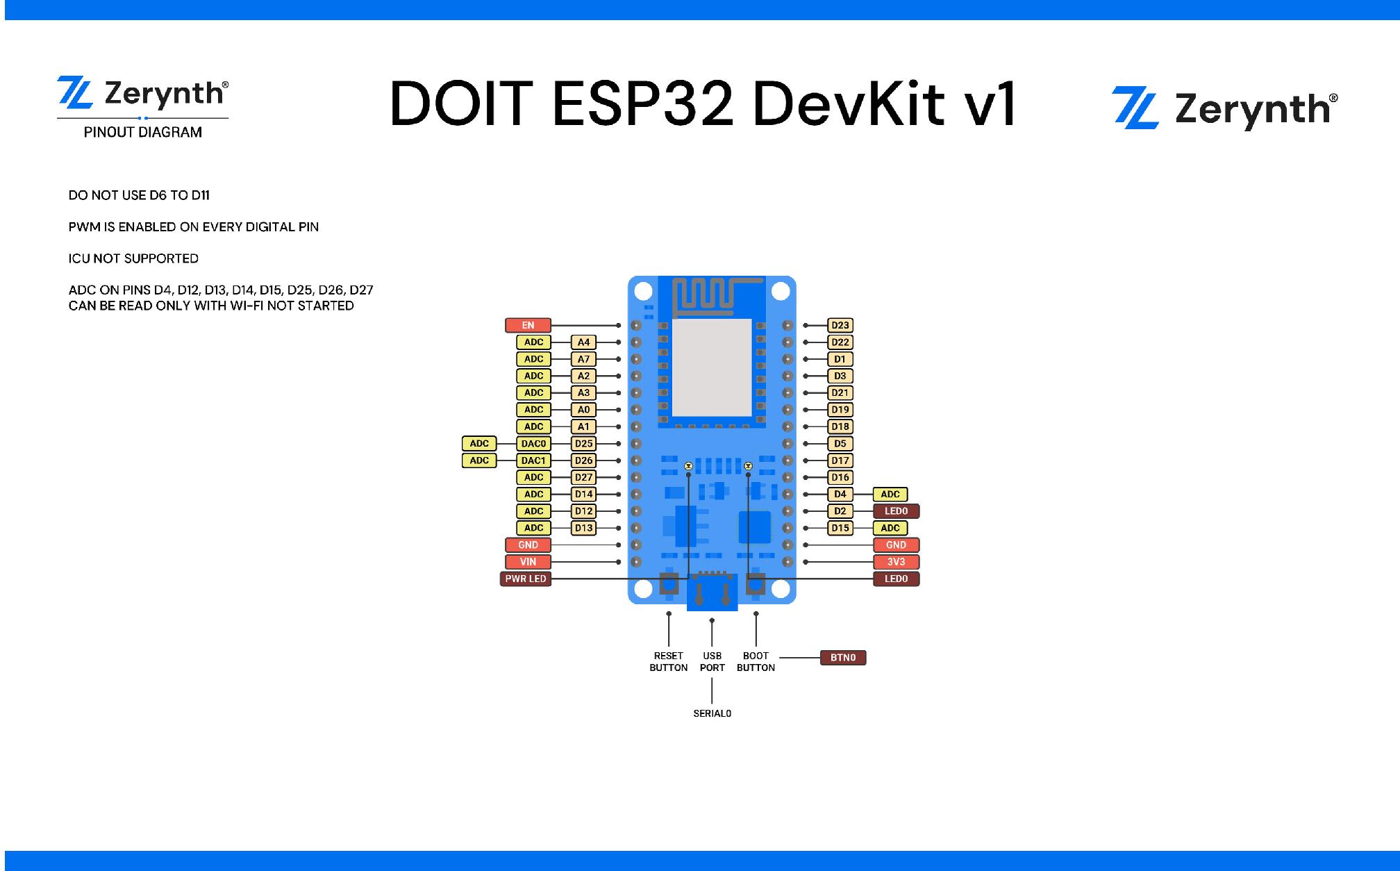
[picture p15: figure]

More info about DOIT Esp32 DevKit v1 can be found here.

## Flash Layout

The internal flash of the ESP32 module is organized in a single flash area with pages of 4096 bytes each. The flash starts at address 0x00000, but many areas are reserved for Esp32 IDF SDK and Zerynth VM. There exist two different layouts based on the presence of BLE support.

In particular, for non-BLE VMs:

Start address | Size | Content
0x00009000 | 16Kb | Esp32 NVS area
0x0000D000 | 8Kb | Esp32 OTA data
0x0000F000 | 4Kb | Esp32 PHY data
0x00010000 | 1Mb | Zerynth VM
0x00110000 | 1Mb | Zerynth VM (FOTA)
0x00210000 | 512Kb | Zerynth Bytecode
0x00290000 | 512Kb | Zerynth Bytecode (FOTA)
0x00310000 | 512Kb | Free for user storage
0x00390000 | 448Kb | Reserved

For BLE VMs:

Start address | Size | Content
0x00009000 | 16Kb | Esp32 NVS area
0x0000D000 | 8Kb | Esp32 OTA data
0x0000F000 | 4Kb | Esp32 PHY data
0x00010000 | 1216Kb | Zerynth VM
0x00140000 | 1216Kb | Zerynth VM (FOTA)
0x00270000 | 320Kb | Zerynth Bytecode
0x002C0000 | 320Kb | Zerynth Bytecode (FOTA)
0x00310000 | 512Kb | Free for user storage
0x00390000 | 448Kb | Reserved

## Device Summary

- Microcontroller: Tensilica 32-bit Single-/Dual-core CPU Xtensa LX6
- Operating Voltage: 3.3V
- Input Voltage: 7-12V
- Digital I/O Pins (DIO): 25
- Analog Input Pins (ADC): 6
- Analog Outputs Pins (DAC): 2
- UARTs: 3
- SPIs: 2
- I2Cs: 3
- Flash Memory: 4 MB
- SRAM: 520 KB
- Clock Speed: 240 Mhz
- Wi-Fi: IEEE 802.11 b/g/n/e/i:
- Integrated TR switch, balun, LNA, power amplifier and matching network
- WEP or WPA/WPA2 authentication, or open networks

## Power

Power to the DOIT Esp32 DevKit v1 is supplied via the on-board USB Micro B connector or directly via the “VIN” pin. The power source is selected automatically.

The device can operate on an external supply of 6 to 20 volts. If using more than 12V, the voltage regulator may overheat and damage the device. The recommended range is 7 to 12 volts.

## Connect, Register, Virtualize and Program

The DOIT Esp32 DevKit v1 comes with a serial-to-usb chip on board that allows programming and opening the UART of the ESP32 module. Drivers may be needed depending on your system (Mac or Windows) and can be download from the official Espressif documentation page. In Linux systems, the DevKit v1 should work out of the box.

Note

For Linux Platform: to allow the access to serial ports the user needs read/write access to the serial device file. Adding the user to the group, that owns this file, gives the required read/write access:

- Ubuntu distribution –> dialout group
- Arch Linux distribution –> uucp group

Once connected on a USB port, if drivers have been correctly installed, the DevKit v1 device is recognized by Zerynth Studio. The next steps are:

- Select the DevKit v1 on the Device Management Toolbar (disambiguate if necessary);
- Register the device by clicking the “Z” button from the Zerynth Studio;
- Create a Virtual Machine for the device by clicking the “Z” button for the second time;
- Virtualize the device by clicking the “Z” button for the third time.

Note

No user intervention on the device is required for registration and virtualization process

After virtualization, the DevKit v1 is ready to be programmed and the Zerynth scripts uploaded. Just Select the virtualized device from the “Device Management Toolbar” and click the dedicated “upload” button of Zerynth Studio.

Note

No user intervention on the device is required for the uplink process.

## Firmware Over the Air update (FOTA)

The Firmware Over the Air feature allows to update the device firmware at runtime. Zerynth FOTA in the DevKitC device is available for bytecode and VM.

Flash Layout is shown in table below:

Start address | Size | Content
0x00010000 | 1Mb | Zerynth VM (slot 0)
0x00110000 | 1Mb | Zerynth VM (slot 1)
0x00210000 | 512Kb | Zerynth Bytecode (slot 0)
0x00290000 | 512Kb | Zerynth Bytecode (slot 1)

For BLE VMs:

Start address | Size | Content
0x00010000 | 1216Kb | Zerynth VM (slot 0)
0x00140000 | 1216Kb | Zerynth VM (slot 1)

Start address | Size | Content
0x00270000 | 320Kb | Zerynth Bytecode (slot 0)
0x002C0000 | 320Kb | Zerynth Bytecode (slot 1)

For Esp32 based devices, the FOTA process is implemented mostly by using the provided system calls in the IDF framework. The selection of the next VM to be run is therefore a duty of the Espressif bootloader; the bootloader however, does not provide a failsafe mechanism to revert to the previous VM in case the currently selected one fails to start. At the moment this lack of a safety feature can not be circumvented, unless by changing the bootloader. As soon as Espressif relases a new IDF with such feature, we will release updated VMs.

## Secure Firmware

Secure Firmware feature allows to detect and recover from malfunctions and, when supported, to protect the running firmware (e.g. disabling the external access to flash or assigning protected RAM memory to critical parts of the system).

This feature is strongly platform dependent; more information at Secure Firmware - ESP32 section.

## Zerynth Secure Socket

To be able to use Zerynth Secure Socket on esp32 boards NATIVE_MBEDTLS: true must be used instead of

ZERYNTH_SSL: true in the project.yml file.

## Missing features

Not all IDF features have been included in the Esp32 based VMs. In particular the following are missing but will be added in the near future:

- Touch detection support

# Appendix B

# Codes

38

# TRANSMITTER

#include <SPI.h>

#include <LoRa.h>

#include <TinyGPS++.h>

#include <SoftwareSerial.h>

#define LORA_SS 10

#define LORA_RST 9

#define LORA_DIO0 2

#define GPS_RX 4

#define GPS_TX 3

#define USER_BUTTON PC13

SoftwareSerial gpsSerial(GPS_RX, GPS_TX); // RX, TX

TinyGPSPlus gps;

void setup() {

Serial.begin(115200);

gpsSerial.begin(9600);

pinMode(USER_BUTTON, INPUT);

Serial.println("GPS + LoRa Transmitter Initializing...");

LoRa.setPins(LORA_SS, LORA_RST, LORA_DIO0);

if (!LoRa.begin(433E6)) { // 433 MHz

Serial.println("Starting LoRa failed!");

while (1);

}

Serial.println("LoRa Initialized.");

}

void loop() {

while (gpsSerial.available() > 0) {

gps.encode(gpsSerial.read());

}

if (gps.location.isUpdated()) {

float lat = gps.location.lat();

float lon = gps.location.lng();

// Print to Serial Monitor

Serial.print("Lat: "); Serial.print(lat, 6);

Serial.print(" | Lon: "); Serial.println(lon, 6);

String message;

if (digitalRead(USER_BUTTON) == LOW) {

Serial.println(" EMERGENCY BUTTON PRESSED!");

message = "EMERGENCY," + String(lat, 6) + "," + String(lon, 6);

} else {

// Default GPS transmission

message = String(lat, 6) + "," + String(lon, 6);

}

LoRa.beginPacket();

LoRa.print(message);

LoRa.endPacket();

Serial.println("Sent via LoRa: " + message);

delay(1000);

} }

# RECEIVER

#include <SPI.h>

#include <LoRa.h>

#define LORA_SCK 18

#define LORA_MISO 19

#define LORA_MOSI 23

#define LORA_SS 5

#define LORA_RST 14

#define LORA_DIO0 2

void setup() {

Serial.begin(115200);

Serial.println("LoRa Receiver Starting...");

SPI.begin(LORA_SCK, LORA_MISO, LORA_MOSI, LORA_SS);

Serial.println("LoRa Receiver Initialized on 433 MHz");

}

void loop() {

int packetSize = LoRa.parsePacket();

if (packetSize) {

String incoming = "";

while (LoRa.available()) {

incoming += (char)LoRa.read();

}

Serial.print("Received: ");

Serial.println(incoming);

int firstComma = incoming.indexOf(',');

int secondComma = incoming.indexOf(',', firstComma + 1);

if (firstComma > 0 && secondComma == -1) {

float lat = incoming.substring(0, firstComma).toFloat();

float lon = incoming.substring(firstComma + 1).toFloat();

Serial.print("Latitude: "); Serial.println(lat, 6);

Serial.print("Longitude: "); Serial.println(lon, 6);

}

else if (firstComma > 0 && secondComma > 0) {

String alert = incoming.substring(0, firstComma);

float lat = incoming.substring(firstComma + 1, secondComma).toFloat();

float lon = incoming.substring(secondComma + 1).toFloat();

Serial.println(" | EMERGENCY ALERT RECEIVED | ");

Serial.print("Latitude: "); Serial.println(lat, 6);

Serial.print("Longitude: "); Serial.println(lon, 6);

}

Serial.println("---------------------------");

}

}

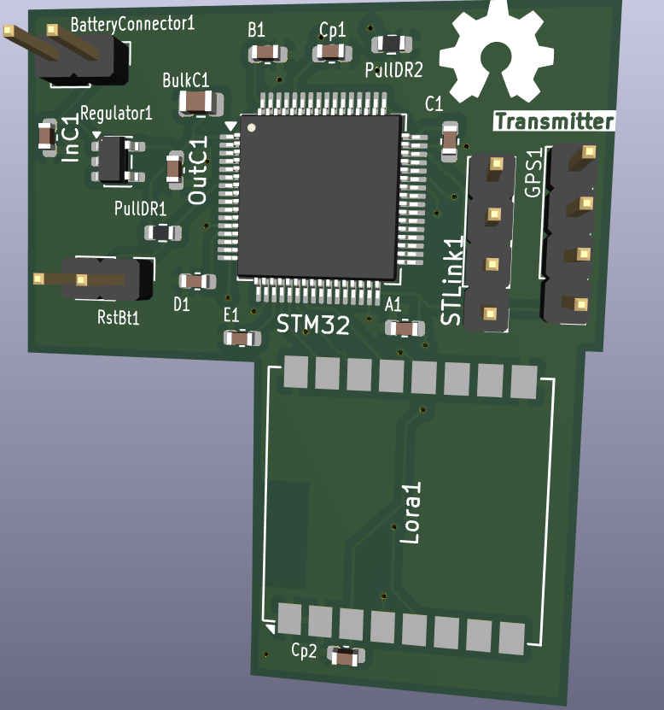
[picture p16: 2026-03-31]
docs/3D_image.png

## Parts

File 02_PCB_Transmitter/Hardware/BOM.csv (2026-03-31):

Reference | Qty | Value | Footprint
A1,B1,C1,Cp1,Cp2,D1,E1 | 7 | 100nF | Capacitor_SMD:C_0603_1608Metric
BatteryConnector1,RstBt1 | 2 |  | Connector_PinHeader_2.54mm:PinHeader_1x02_P2.54mm_Vertical
BulkC1 | 1 | 10uF | Capacitor_SMD:C_0805_2012Metric
GPS1 | 1 | NEO-6M | Connector_PinHeader_2.54mm:PinHeader_1x04_P2.54mm_Vertical
InC1,OutC1 | 2 | 1uF | Capacitor_SMD:C_0603_1608Metric
Lora1 | 1 | Sx1278 | RF_Module:Ai-Thinker-Ra-01-LoRa
PullDR1,PullDR2 | 2 | 10K | Resistor_SMD:R_0603_1608Metric
Regulator1 | 1 | AP2112K-3.3 | Package_TO_SOT_SMD:SOT-23-5
STLink1 | 1 | - | Connector_PinHeader_2.54mm:PinHeader_1x04_P2.54mm_Vertical
STM32 | 1 | STM32F103RBTx | Package_QFP:LQFP-64_10x10mm_P0.5mm

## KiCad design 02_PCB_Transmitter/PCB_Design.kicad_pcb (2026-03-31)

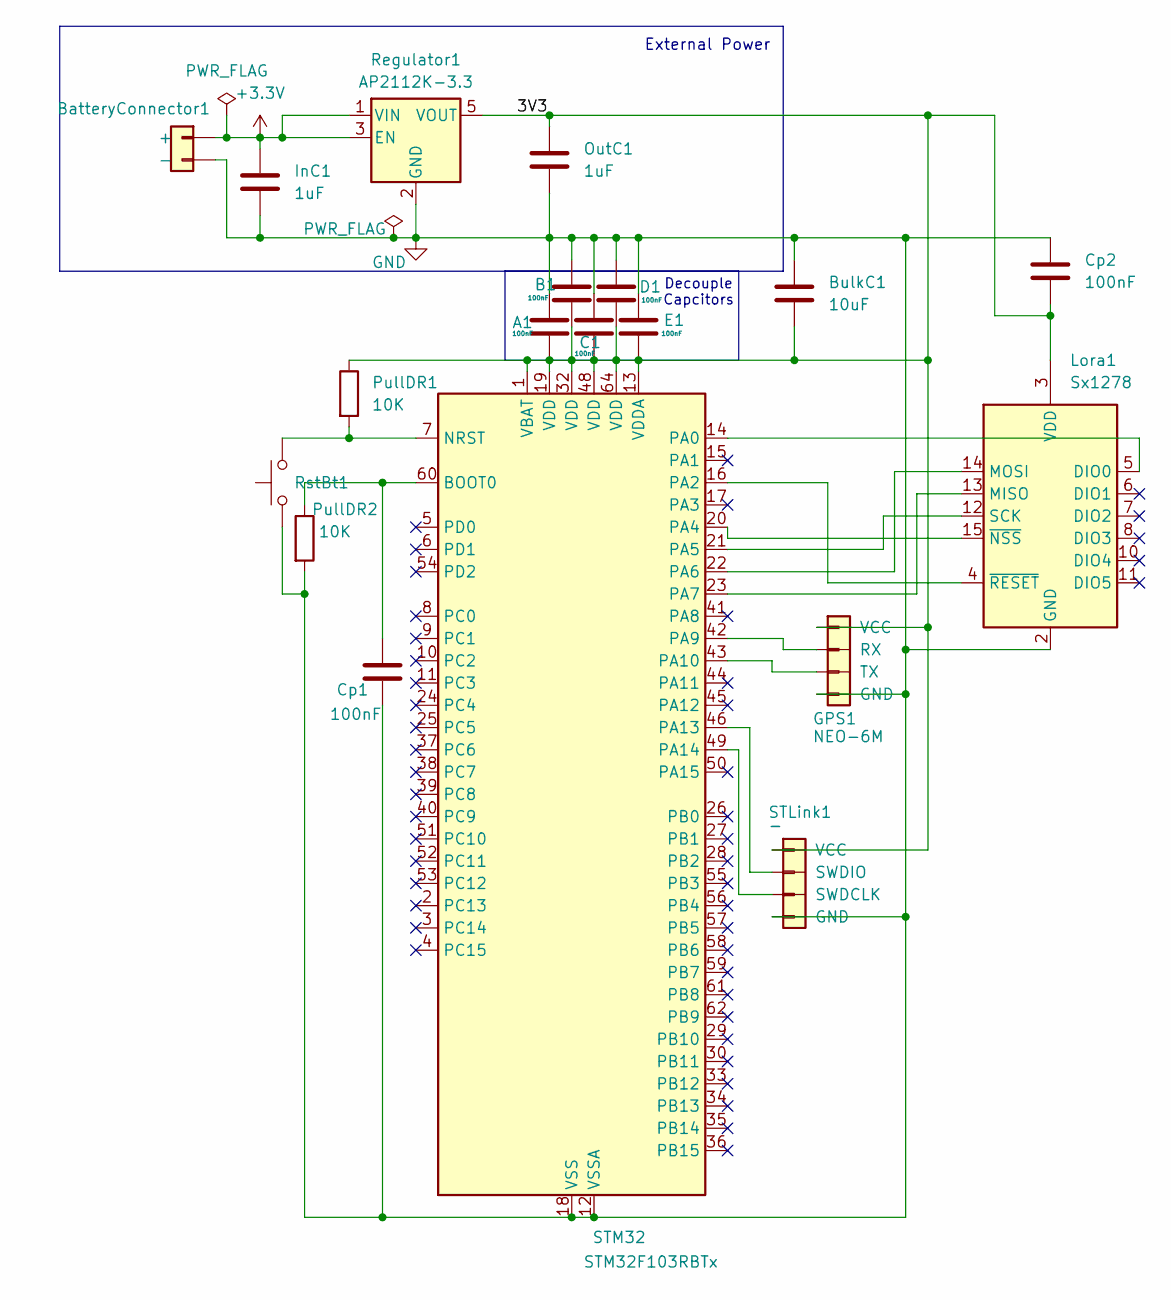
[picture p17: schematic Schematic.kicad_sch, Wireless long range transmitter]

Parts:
A1: 100nF; C_0603_1608Metric
B1: 100nF; C_0603_1608Metric
BatteryConnector1: PinHeader_1x02_P2.54mm_Vertical
BulkC1: 10uF; C_0805_2012Metric
C1: 100nF; C_0603_1608Metric
Cp1, Cp2: 100nF; C_0603_1608Metric
D1: 100nF; C_0603_1608Metric
E1: 100nF; C_0603_1608Metric
GPS1: NEO-6M; PinHeader_1x04_P2.54mm_Vertical
InC1: 1uF; C_0603_1608Metric
Lora1: Sx1278; Ai-Thinker-Ra-01-LoRa
OutC1: 1uF; C_0603_1608Metric
PullDR1, PullDR2: 10K; R_0603_1608Metric
Regulator1: AP2112K-3.3; SOT-23-5
RstBt1: PinHeader_1x02_P2.54mm_Vertical
STLink1: -; PinHeader_1x04_P2.54mm_Vertical
STM32: STM32F103RBTx; LQFP-64_10x10mm_P0.5mm

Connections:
+3.3V: BatteryConnector1.1 (+), InC1.1, Regulator1.1 (VIN), Regulator1.3 (EN)
/3V3: A1.2, B1.2, BulkC1.2, C1.2, Cp2.2, D1.2, E1.2, GPS1.1 (VCC), Lora1.3 (VDD), OutC1.1, PullDR1.1, Regulator1.5 (VOUT), STLink1.1 (VCC), STM32.1 (VBAT), STM32.13 (VDDA), STM32.19 (VDD), STM32.32 (VDD), STM32.48 (VDD), STM32.64 (VDD)
GND: A1.1, B1.1, BatteryConnector1.2 (-), BulkC1.1, C1.1, Cp1.2, Cp2.1, D1.1, E1.1, GPS1.4 (GND), InC1.2, Lora1.1 (GND), Lora1.2 (GND), Lora1.9 (GND), Lora1.16 (GND), OutC1.2, PullDR2.2, Regulator1.2 (GND), RstBt1.1, STLink1.4 (GND), STM32.12 (VSSA), STM32.18 (VSS), STM32.31 (VSS), STM32.47 (VSS), STM32.63 (VSS)
unnamed: GPS1.2 (RX), STM32.42 (PA9)
unnamed: GPS1.3 (TX), STM32.43 (PA10)
unnamed: Lora1.5 (DIO0), STM32.14 (PA0)
unnamed: Lora1.13 (MISO), STM32.23 (PA7)
unnamed: Lora1.14 (MOSI), STM32.22 (PA6)
unnamed: Lora1.12 (SCK), STM32.21 (PA5)
unnamed: Lora1.15 (~NSS), STM32.20 (PA4)
unnamed: Lora1.4 (~RESET), STM32.16 (PA2)
unnamed: STLink1.3 (SWDCLK), STM32.49 (PA14)
unnamed: STLink1.2 (SWDIO), STM32.46 (PA13)
unnamed: Cp1.1, PullDR2.1, STM32.60 (BOOT0)
unnamed: PullDR1.2, RstBt1.2, STM32.7 (NRST)

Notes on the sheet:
External Power
Decouple Capcitors

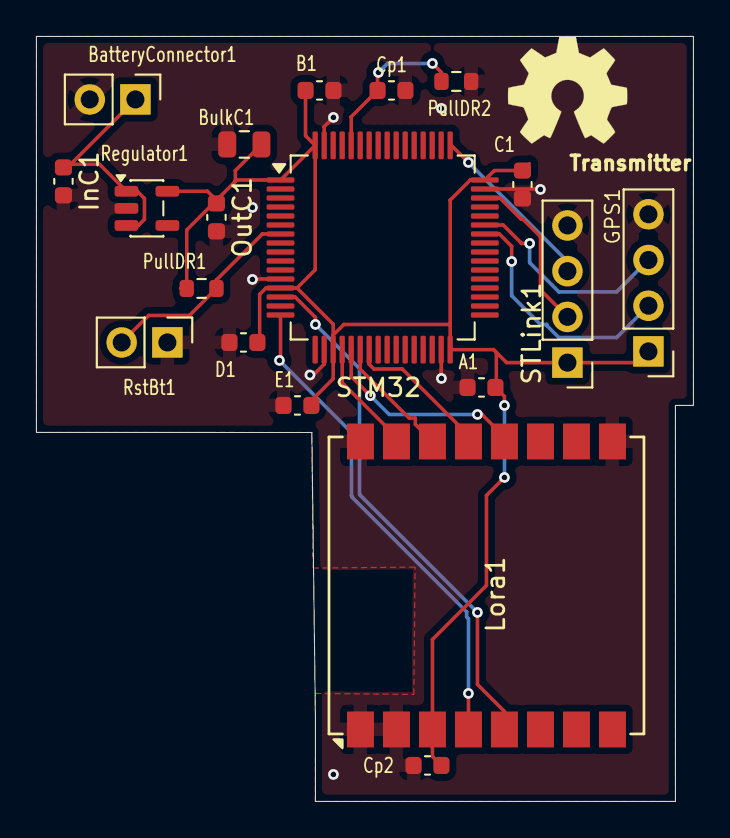
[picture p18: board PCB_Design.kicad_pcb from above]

Board: 2 copper layers, 36.5 x 42.5 mm, 19 parts (0 on the bottom side), 15 nets.

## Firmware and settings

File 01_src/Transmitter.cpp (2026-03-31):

#include <SPI.h>
#include <LoRa.h>
#include <TinyGPS++.h>
#include <SoftwareSerial.h>

// LoRa Pins
#define LORA_SS   10
#define LORA_RST  9
#define LORA_DIO0 2

// GPS Pins
#define GPS_RX 4
#define GPS_TX 3

// User Button (STM32)
#define USER_BUTTON PC13

SoftwareSerial gpsSerial(GPS_RX, GPS_TX);
TinyGPSPlus gps;

void setup() {
    Serial.begin(115200);
    gpsSerial.begin(9600);
    pinMode(USER_BUTTON, INPUT);

    Serial.println("GPS + LoRa Transmitter Initializing...");

    LoRa.setPins(LORA_SS, LORA_RST, LORA_DIO0);
    if (!LoRa.begin(433E6)) {
        Serial.println("Starting LoRa failed!");
        while (1);
    }

    Serial.println("LoRa Initialized.");
}

void loop() {
    // Read GPS data
    while (gpsSerial.available() > 0) {
        gps.encode(gpsSerial.read());
    }

    if (gps.location.isUpdated()) {
        float lat = gps.location.lat();
        float lon = gps.location.lng();

        Serial.print("Lat: "); Serial.print(lat, 6);
        Serial.print(" | Lon: "); Serial.println(lon, 6);

        String message;

        // Emergency Button Check
        if (digitalRead(USER_BUTTON) == LOW) {
            Serial.println("EMERGENCY BUTTON PRESSED!");
            message = "EMERGENCY," + String(lat, 6) + "," + String(lon, 6);
        } else {
            message = String(lat, 6) + "," + String(lon, 6);
        }

        // Send via LoRa
        LoRa.beginPacket();
        LoRa.print(message);
        LoRa.endPacket();

        Serial.println("Sent via LoRa: " + message);
        delay(1000);
    }
}

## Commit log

2026-03-31 Implement GPS + LoRa transmitter with emergency button
    This code initializes a LoRa transmitter that reads GPS data and sends it over LoRa. It includes emergency button functionality to send an emergency message.
2026-03-31 Revise README structure and add technical details
    Updated the README to reorganize sections and add technical details about the circuit and PCB design.
2026-03-31 Remove Circuit Implementation section from README
    Removed Circuit Implementation section and image from README.
